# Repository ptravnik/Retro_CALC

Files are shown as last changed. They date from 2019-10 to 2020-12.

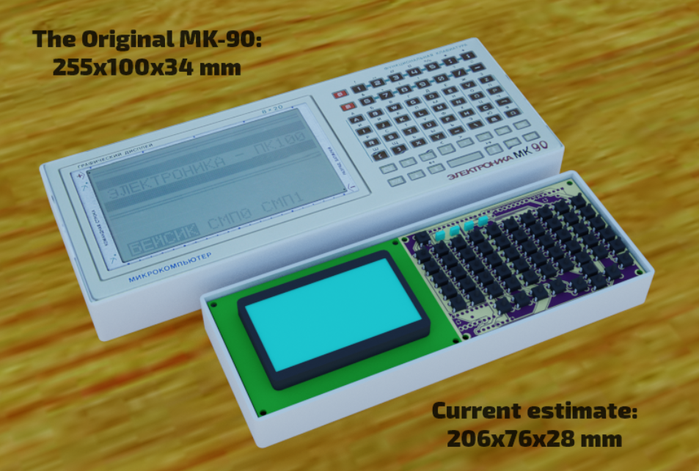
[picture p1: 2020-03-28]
RetroRPN_ESP32/Schematics/Plots/RetroCalculator_Mockup2_Rendering.png

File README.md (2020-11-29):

# Retro_CALC

The ultimate goal is to build a powerful RPN calculator, programmable in BASIC-like language

## The FIRST mockup version:

1. Arduino MEGA 2560
1. [Arduino MEGA SRAM shield](https://hackaday.io/project/21561-arduino-mega-2560-32kb-ram-shield) (my PCB is modified for 56k RAM instead of 32 in the original version)
1. Arduino SD card reader; this version is for Uno, but runs on Mega with pins 10-13 using Soft SPI
1. Piezo speaker on line 9
1. Hardware keyboard on lines A0-A4
1. LCD screen 128x64 pixels on SPI

This code development is abandoned.

## The SECOND mockup version:

1. ESP32 Dev Module
1. Micro SD card reader on VSPI 5, 18, 19, 23
1. Hardware keyboard on lines 25-27 and 32, 33; pin 34 is used for power switch
1. LCD screen 128x64 pixels on HSPI 12-15 
1. Arduino Micro Pro 3.3V, 8 MHz as a "keyboard/mouse injector"

The code is fully ported and tested on the ESP-32 platform. Final version of Keyboard PCB (KBD-2090) has been tested.

## The THIRD mockup version:

1. ESP32 Dev Module
1. Micro SD card reader on VSPI 5, 18, 19, 23
1. Hardware keyboard on lines 25-27 and 32, 33; pin 34 is used for power switch
1. TFT screen 480x320 pixels on HSPI 12-15
1. 2xLiPo batteries (4000 mAh), charger and power management
1. Real-Time Clock based on DS3231 chip
1. Arduino Micro Pro 3.3V, 8 MHz as a "peripheral controller"

This mockup is under development. Both BW LCD and Color TFT are likely to be supported. 

# Build Instructions

## To build for Arduino Mega 2560
1. Tested on Arduino IDE 1.18.10.
1. Install 3 libraries: [U8g2](https://github.com/ptravnik/Retro_CALC/tree/master/U8g2) for the LCD, [SD2](https://github.com/ptravnik/Retro_CALC/tree/master/SD2), and [HWKbd](https://github.com/ptravnik/Retro_CALC/tree/master/HWKbd) for the keyboard. Alternatively just copy the same into the Arduino libraries folder (will not install the examples).
1. Copy the source, [RetroRPN_Arduino](https://github.com/ptravnik/Retro_CALC/tree/master/RetroRPN_Arduino), to any convenient folder and open with Arduino IDE.
1. Select the board as **Arduino Mega or Mega 2560**, processor **ATMega 2560**, compile and upload as usual.

## To build for ESP32 Dev Board
1. Tested on Arduino IDE 1.18.10. and 1.18.12 (VSCode IDE also can be used if Arduino IDE is installed).
1. Install 2 libraries: [U8g2](https://github.com/ptravnik/Retro_CALC/tree/master/U8g2) for the LCD and [HWKbd](https://github.com/ptravnik/Retro_CALC/tree/master/HWKbd) for the keyboard. Alternatively just copy the same into the Arduino libraries folder (will not install the examples).
1. Copy the source, [RetroRPN_ESP32](https://github.com/ptravnik/Retro_CALC/tree/master/RetroRPN_ESP32), to any convenient folder and open with Arduino IDE.
1. Validate which version of hardware keyboard is connected: the production layout uses different h file as the buttons\' position is different from the early mock-up.
1. Select the board as **ESP32 Dev Module**, compile and upload as usual. Dev module requires you to hold **BOOT** down for security reasons; on my module (v 1) this pin is not exposed, so must be done with the button on the module itself. Your board may have this on GPIO 00 pin - wiring to an external button is recommended.

## To build the Keyboard Injector or Peripheral Controller:
1. Tested only with cheap Chinese clones of Sparkfun Pro Micro on Arduino IDE 1.18.10 and 1.18.12.
1. Carefully follow the [install instructions from Sparkfun](https://learn.sparkfun.com/tutorials/pro-micro--fio-v3-hookup-guide/all)
1. Download the [code from github](https://github.com/ptravnik/Retro_CALC/tree/master/Keyboard_Injector_Micro or https://github.com/ptravnik/Retro_CALC/tree/master/MK2090_Peripheral_Controller) 
1. Select the board as **Sparkfun Pro Micro** and the processor as **ATMega 32U4 3.3V, 8MHz** or **ATMega 5.0V 16MHz** version (depending on the one you have); **CAUTION** "Leonardo" may work for 5V / 16 MHz boards, but will surely brick a 3.3V version!
1. Select the board's port
1. Upload to board (shorting Reset to Ground may be required after the interface says "Uploading...")

## Automated testing
1. Place the content of [testing folder](https://github.com/ptravnik/Retro_CALC/tree/master/BASIC_Tests) into the root of the SD card.
1. Insert the SD into the calculator and cycle power button.
1. Upon the calculator wake-up (or new firmware install from the IDE + reboot), issue command **RUN** via Serial Monitor.

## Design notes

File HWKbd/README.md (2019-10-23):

  Hardware keyboard for Arduino with an SPI-like interface
  Copyright (c) 2019 Pavel Travnik.  All right reserved.

  This library is free software; you can redistribute it and/or
  modify it under the terms of the GNU Lesser General Public
  License as published by the Free Software Foundation; either
  version 2.1 of the License, or (at your option) any later version.

  This library is distributed in the hope that it will be useful,
  but WITHOUT ANY WARRANTY; without even the implied warranty of
  MERCHANTABILITY or FITNESS FOR A PARTICULAR PURPOSE.  See the GNU
  Lesser General Public License for more details.

  You should have received a copy of the GNU Lesser General Public
  License along with this library; if not, write to the Free Software
  Foundation, Inc., 51 Franklin St, Fifth Floor, Boston, MA  02110-1301  USA

  Hardware Notes.
  
  The keyboard communicates with Arduino via J1:
  1. POWER - connect to +5 V on Mega or +3.3V on Duo
  2. KBD_RESET - output, any digital pin
  3. KBD_CLOCK - output, any digital pin
  4. KBD_READ - input (no pullup!), any digital pin
  5. LED_RESET - output, any digital pin
  6. LED_CLOCK - output, any digital pin
  7. RESET - connect to Arduino RESET (optional)
  8. GROUND
  To read the keyboard, send a pulse to KBD_RESET and read
  the first button state from KBD_READ (HIGH means "pressed").
  Then, continue sending pulses on KBD_CLOCK to read buttons
  2, 3, 4, etc.
  To set the LEDs, send a pulse to LED_RESET and cycle
  LED_CLOCK from 0 to 15 times, which corresponds to 16 binary states.
  Note that the software presimes that no PWM is sent to the keyboard ports!

  Software Notes.
  The keyboard communicates in UTF-8. The current implementation supports
  8 reading modes:
  0. English character set, small letters, numbers
  1. SHIFT. English character set, capital letters, punctuation marks.
  2. F1 - additional letters and macros in English
  3. F2 - additional letters and macros in English
  4. LANG - national language mode (currently only Cyrillic is implemented)
  5. SHIFT+LANG - capital letters for Cyrillic
  6. F1+LANG - additional letters and macros in national language
  7. F2+LANG - additional letters and macros in national language
  
  The key codes are composed of 16-bit integers, 8 numbers per button
  (by the number of modes). The bit pattern is as following:
  0MMM0000 cccccccc
  1MMMaaaa aaaaaaaa
  MMM - the next mode (from 0 to 7)
  cccccccc - a single-byte Unicode character (if >128, it is a control character, such as an arrow)
  aaaaa aaaaaaaaa - a 12-bit shift in the macros table;
  the latter is composed of null-terminated strings, up to 4k in length.

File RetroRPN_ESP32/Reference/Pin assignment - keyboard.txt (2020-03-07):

Hardware keyboard interfaces:

Primary J1:
1 VDD (3 to 15 Volts are OK, the logic level will change correspondingly)
2 KBD RESET
3 KBD CLOCK
4 KBD READ
5 LED RESET
6 LED CLOCK
7 Host RESET
8 GROUND

J2 is for connecting additional buttons or other devices:
1 VDD (pass-through from J1)
2-11 COLUMNS 0-9
12 ROW 7
13 ROW 8
14 GROUND

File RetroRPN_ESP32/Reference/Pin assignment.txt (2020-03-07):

ESP32 Dev module pins:

// 01 - TX0
// 02 - In-built LED (SD activity)
// 03 - RX0
// 04 - SD insert sensor (DET_A)
// 05 - VSPI CSO - SD Select (DAT3)
// 06 to 11 - NA (Dev module not exposing)
// 12 - HSPI MISO LCD Data (R/W)
// 13 - HSPI MOSI LCD Reset (RESET)
// 14 - HSPI CLK LCD Clock (E)
// 15 - HSPI CSO LCD Select (RS)
// 16 - RX2 (serial to Pro Micro PIN 8)
// 17 - TX2 (serial to Pro Micro PIN 9)
// 18 - VSPI CLK - SD Clock (CLK)
// 19 - VSPI MISO - SD out (DAT0)
// 20 - NA
// 21 - LCD LED PWM
// 22 - LCD POWER (this model does not have sleep)
// 23 - VSPI MOSI - SD command (CMD)
// 24 - NA
// 25 - KBD CLK
// 26 - KBD RST
// 27 - KBD_LED CLK
// 28 to 31 - NA
// 32 - KBD_LED RST
// 33 - KBD DATA
// 34 - POWER ON/OFF
// 35 - (input only) Pro Micro Alive pin 7

Pro Micro pins:

// 07 - Pro Micro is alive
// 08, 09 - TX, RX for software serial
// 10 - optional status pin

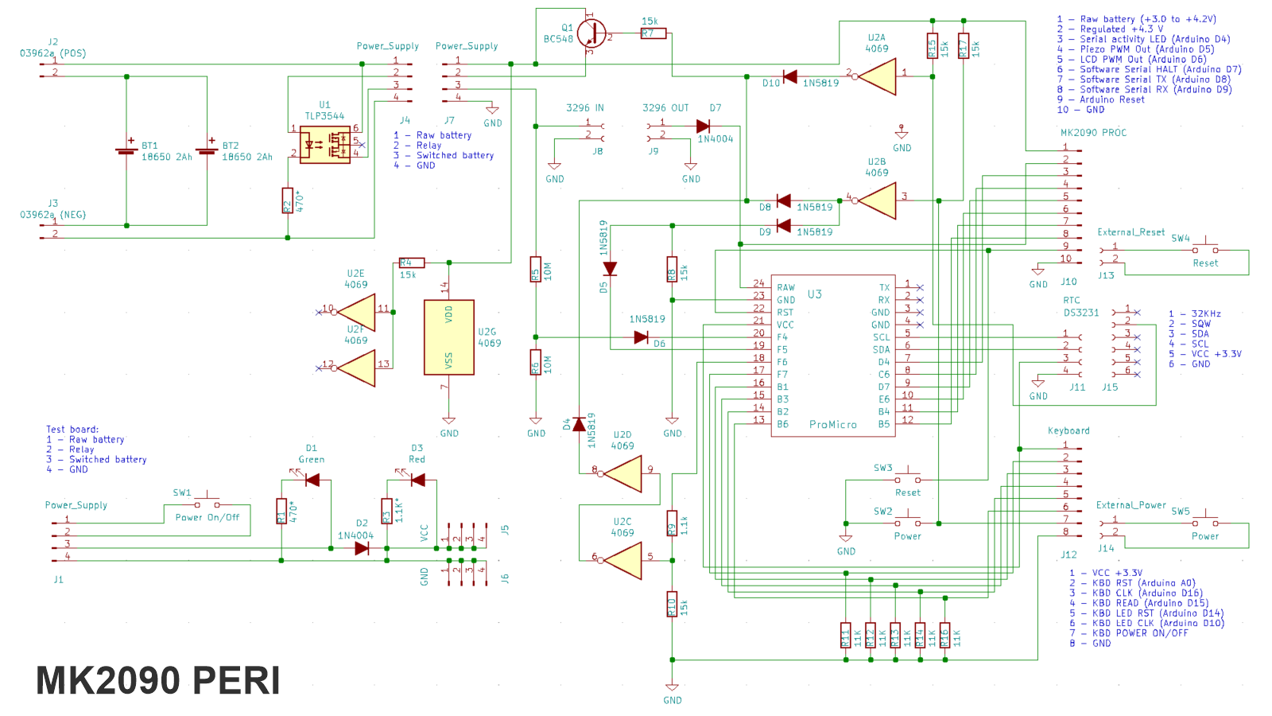
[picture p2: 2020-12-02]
MK2090_Peripheral_Controller/reference/Peripherals_Board_Schematics.png

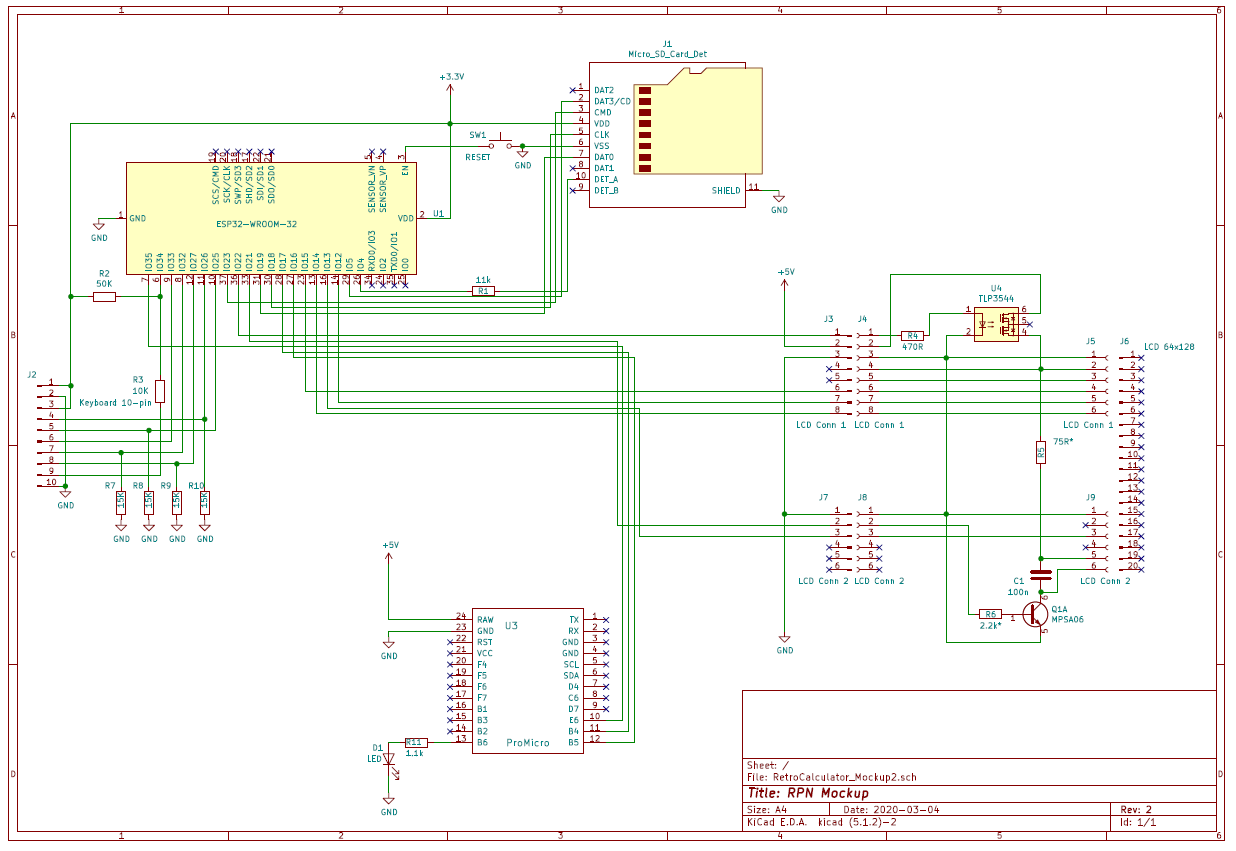
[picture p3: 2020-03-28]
RetroRPN_ESP32/Schematics/Plots/RetroCalculator_Mockup2_Schematics.png

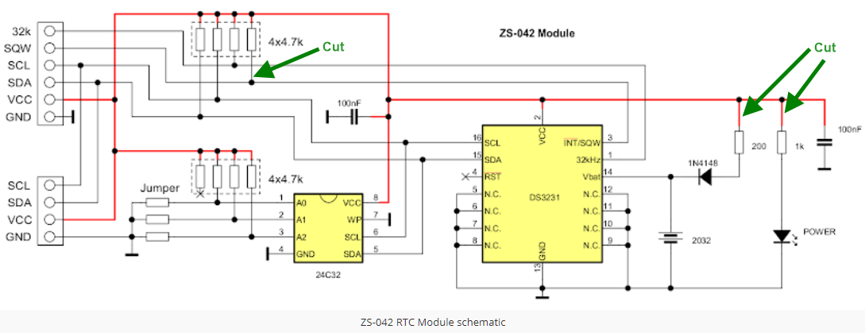
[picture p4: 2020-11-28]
MK2090_Peripheral_Controller/reference/ZS-042 modification.png

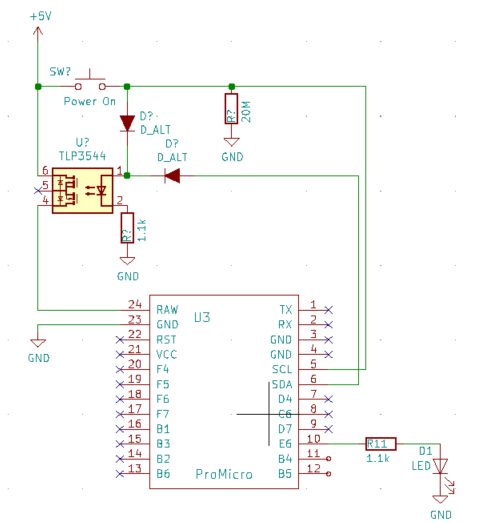
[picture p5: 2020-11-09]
MK2090_Peripheral_Controller/reference/Basic_Power.png

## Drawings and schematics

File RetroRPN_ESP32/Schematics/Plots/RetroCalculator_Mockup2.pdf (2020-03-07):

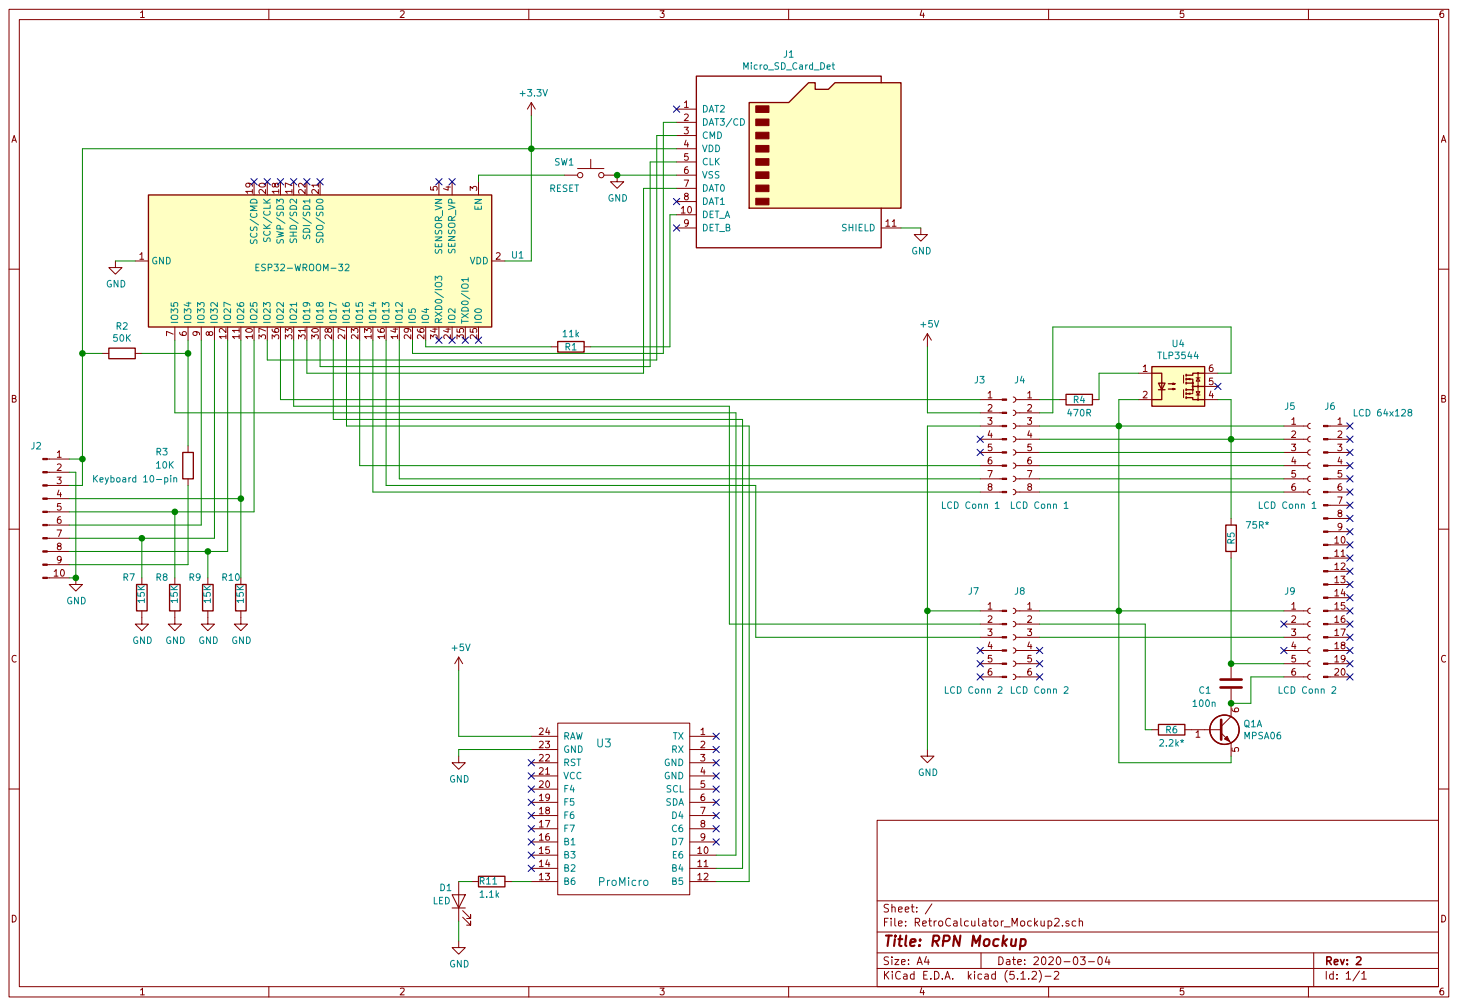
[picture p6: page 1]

9 U1 ESP32-WROOM-32 DAT2 1 DET_A 10 SHIELD 11 DAT3/CD 2 CMD 3 VDD 4 CLK 5 VSS 6 DAT0 7 DAT1 8 DET_B 9

File: RetroCalculator_Mockup2.sch Sheet: /
Id: 1/1 Title: RPN Mockup

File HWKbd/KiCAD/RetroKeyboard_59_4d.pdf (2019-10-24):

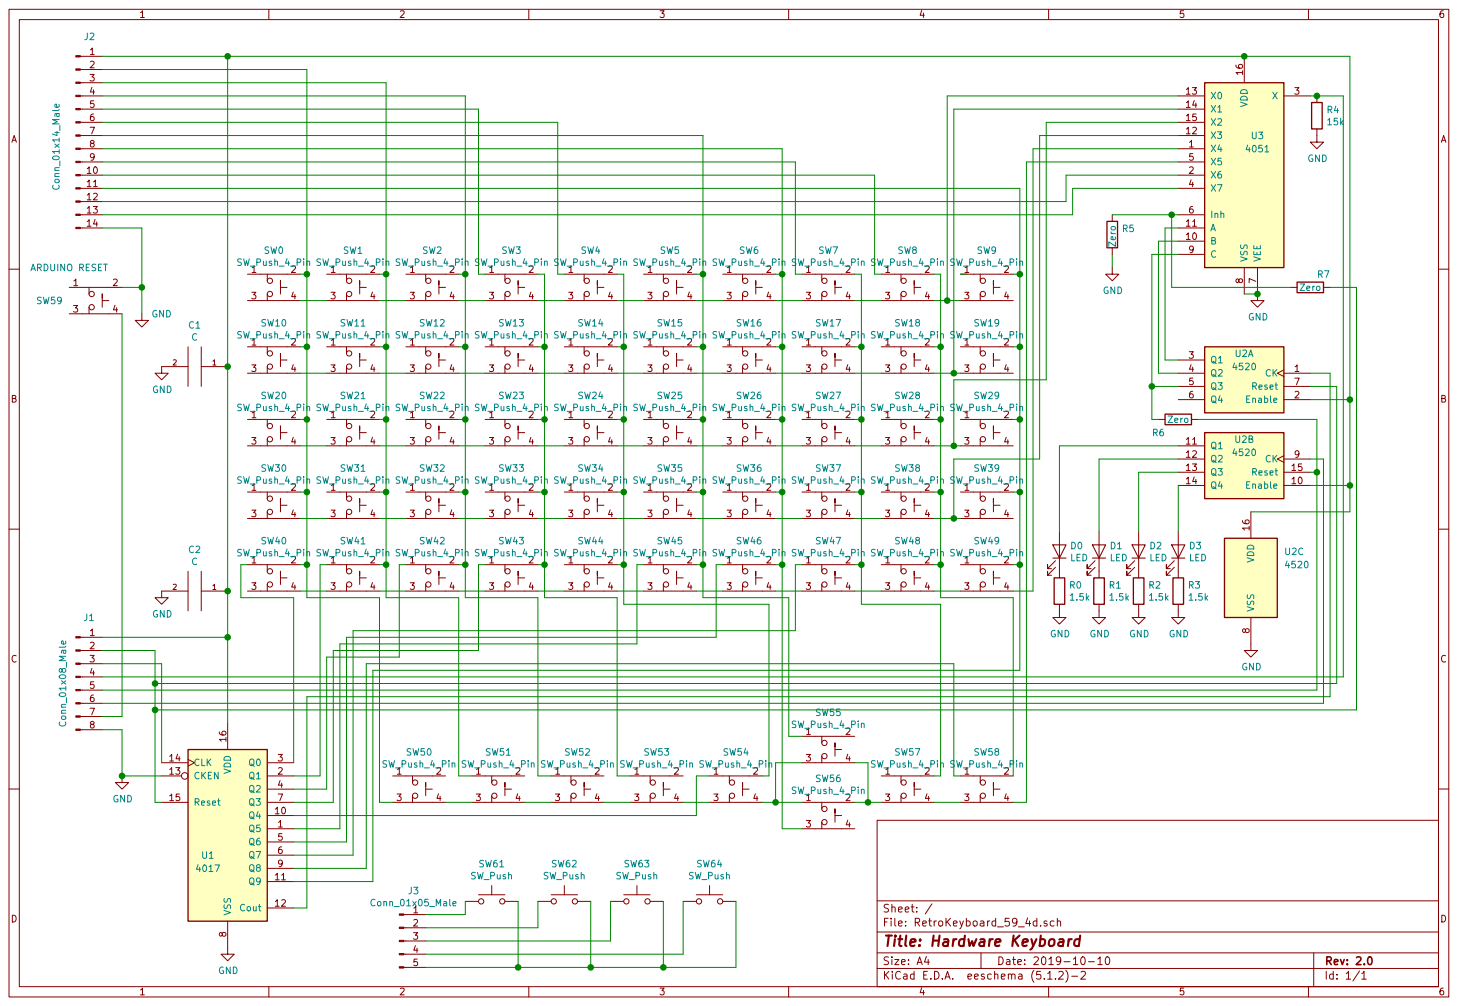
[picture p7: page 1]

Id: 1/1 Title: Hardware Keyboard

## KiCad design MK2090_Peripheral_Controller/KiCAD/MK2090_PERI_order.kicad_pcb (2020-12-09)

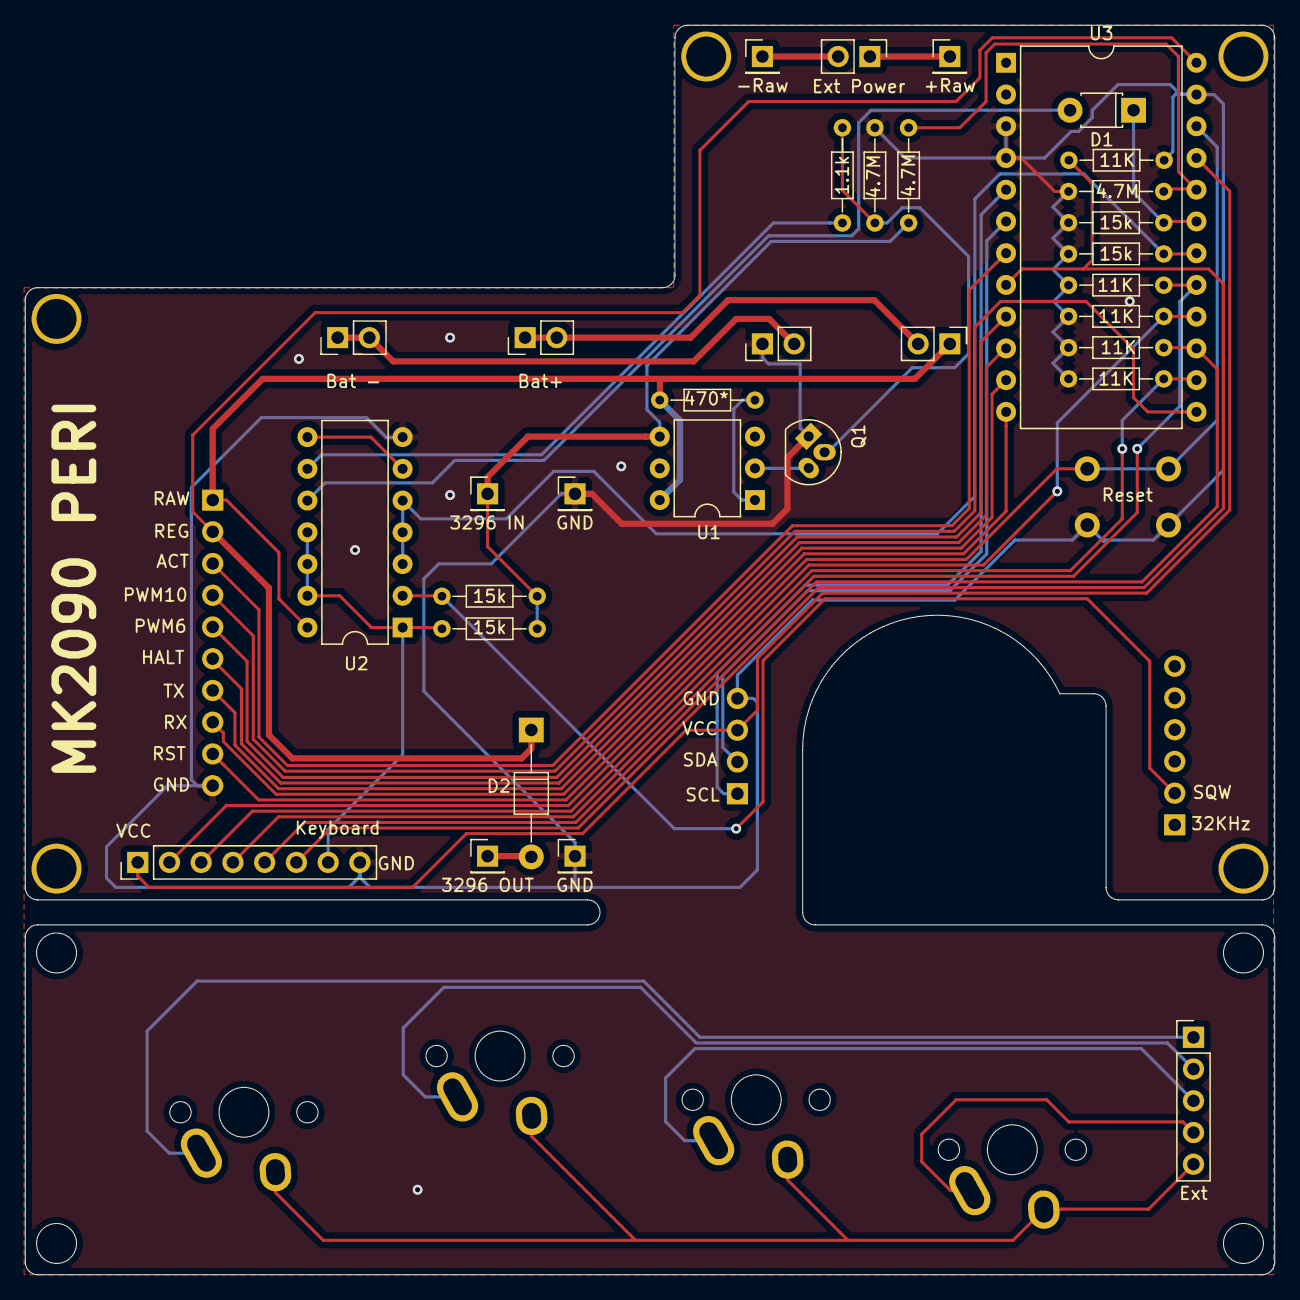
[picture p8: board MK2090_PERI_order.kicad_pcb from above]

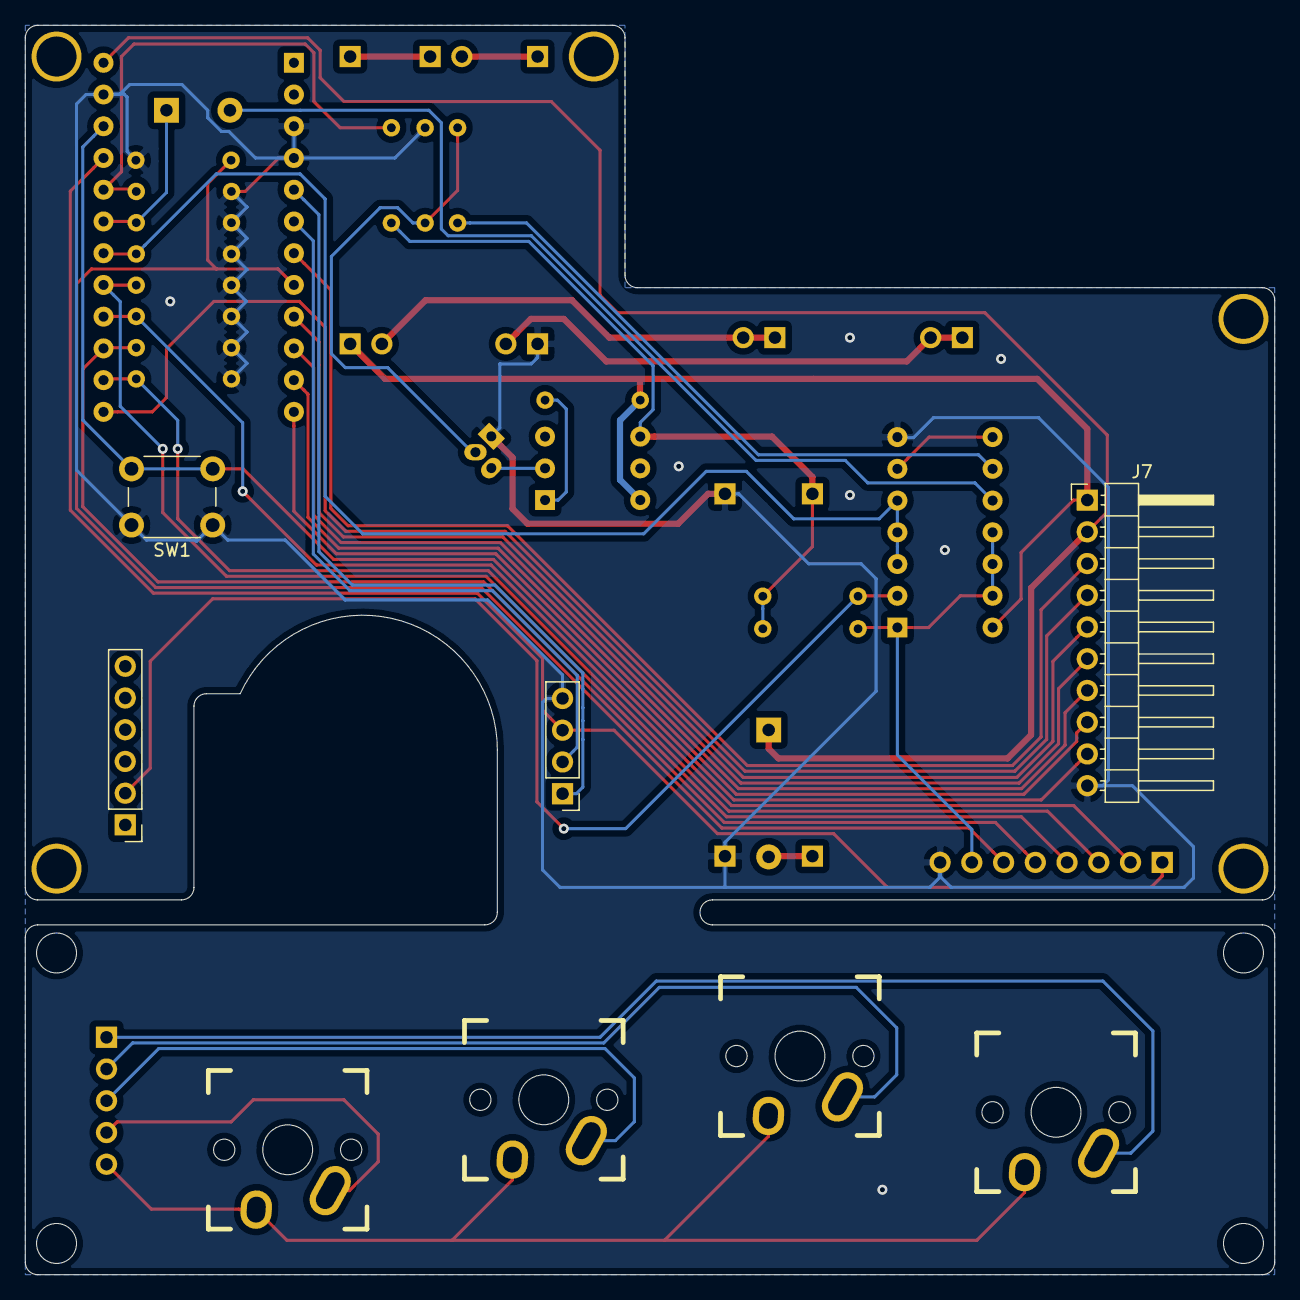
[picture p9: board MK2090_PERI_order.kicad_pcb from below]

Board: 2 copper layers, 100.0 x 100.0 mm, 46 parts (8 on the bottom side), 40 nets.

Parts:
D1: 1N5819; D_T-1_P5.08mm_Horizontal
D2: 1N4004; D_T-1_P10.16mm_Horizontal
HOLE_M3, HOLE_M3#2, HOLE_M3#3, HOLE_M3#4, HOLE_M3#5: VAL**; HOLE_M3
J1: +Raw; Pin_Header_Straight_1x01_Pitch2.54mm
J2: -Raw; Pin_Header_Straight_1x01_Pitch2.54mm
J3: 03962a (POS); Pin_Header_Straight_1x02_Pitch2.54mm
J4: 03962a (NEG); Pin_Header_Straight_1x02_Pitch2.54mm
J5: 3296 IN; Pin_Header_Straight_1x01_Pitch2.54mm
J6, J12: GND; Pin_Header_Straight_1x01_Pitch2.54mm
J7: MK2090 PROC; Pin_Header_Angled_1x10_Pitch2.54mm
J8: Keyboard; Pin_Header_Straight_1x08_Pitch2.54mm
J9: RTC; Pin_Header_Straight_1x04_Pitch2.54mm
J10: DS3231; Pin_Header_Straight_1x06_Pitch2.54mm
J11: 3296 OUT; Pin_Header_Straight_1x01_Pitch2.54mm
J13: Ext Power; Pin_Header_Straight_1x02_Pitch2.54mm
J14: Bat+; Pin_Header_Straight_1x02_Pitch2.54mm
J15: Bat -; Pin_Header_Straight_1x02_Pitch2.54mm
J16: Ext; Pin_Header_Straight_1x05_Pitch2.54mm
Q1: 2N7000; TO-92_Molded_Narrow_Oval
R1: 470*; R_Axial_DIN0204_L3.6mm_D1.6mm_P7.62mm_Horizontal
R2, R7, R8: 4.7M; R_Axial_DIN0204_L3.6mm_D1.6mm_P7.62mm_Horizontal
R3: 1.1k; R_Axial_DIN0204_L3.6mm_D1.6mm_P7.62mm_Horizontal
R4, R5, R6, R9: 15k; R_Axial_DIN0204_L3.6mm_D1.6mm_P7.62mm_Horizontal
R10, R11, R12, R13, R14: 11K; R_Axial_DIN0204_L3.6mm_D1.6mm_P7.62mm_Horizontal
SW1: Reset; SW_PUSH_6mm
SW2: E; Mx_Alps_100
SW3: A; Mx_Alps_100
SW4: L; Mx_Alps_100
SW5: Spec; Mx_Alps_100
U1: TLP3544; DIP-6_W7.62mm
U2: 4023; DIP-14_W7.62mm
U3: ProMicro; DIP-24_W15.24mm

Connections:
GND: J4.1, J6.1, J7.10, J8.8, J9.4, J12.1, Q1.1, R2.1, R6.1, R8.1, R9.1, R10.1, R11.1, R12.1, R13.1, R14.1, SW1.1, U2.7, U3.3, U3.4, U3.23
unnamed: D1.1, R9.2, U3.19
unnamed: D1.2, U2.10
unnamed: D2.1, J7.2, U3.24
unnamed: D2.2, J11.1
unnamed: J1.1, J13.1
unnamed: J3.1, J7.1, R1.2, U1.6, U2.14
unnamed: J5.1, R4.2, R5.2, R7.2, U1.4
unnamed: J7.3, U3.7
unnamed: J7.4, U3.13
unnamed: J7.5, U3.9
unnamed: J7.6, U3.10
unnamed: J7.7, U3.11
unnamed: J7.8, U3.12
unnamed: J7.9, SW1.2, U3.22
unnamed: J8.1, J9.3, U3.21
unnamed: J8.2, R11.2, U3.16
unnamed: J8.3, R13.2, U3.14
unnamed: J8.4, R10.2, U3.17
unnamed: J8.5, R12.2, U3.15
unnamed: J8.6, R14.2, U3.8
unnamed: J8.7, R4.1, U2.1, U2.11, U2.12, U2.13
unnamed: J9.1, U3.5
unnamed: J9.2, U3.6
unnamed: J10.2, R5.1, U2.2
unnamed: J2.1, J13.2
unnamed: J3.2, J14.1, J14.2
unnamed: J4.2, J15.1, J15.2
unnamed: J16.1, SW2.1
unnamed: J16.2, SW3.1
unnamed: J16.3, SW4.1
unnamed: J16.4, SW5.1
unnamed: J16.5, SW2.2, SW3.2, SW4.2, SW5.2
unnamed: Q1.2, R2.2, R3.1
unnamed: Q1.3, U1.2
unnamed: R1.1, U1.1
unnamed: R3.2, U2.9
unnamed: R6.2, U2.3, U2.4, U2.5, U3.18
unnamed: R7.1, R8.2, U3.20
unnamed: U2.6, U2.8

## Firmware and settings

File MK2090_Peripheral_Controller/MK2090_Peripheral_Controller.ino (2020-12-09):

////////////////////////////////////////////////////////

/* RetroRPN - "Электроника МК-90" reborn
  Copyright (c) 2020 Mike Yakimov.  All rights reserved.

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
  You should have received a copy of the GNU Lesser General Public
  License along with this library; if not, write to the Free Software
  Foundation, Inc., 51 Franklin St, Fifth Floor, Boston, MA  02110-1301  USA
*/

////////////////////////////////////////////////////////
//
// This is a hardware companion to ESP32 Retro Calculator (modern reincarnation of the Soviet Электроника-90) 
// Implementation is for Sparkfun Micro Pro module (3.3 V) or valid clones
//
// Functionality:
// (1) Receive inputs from PC via USB Serial, perform conversion from UTF8 to CP1251, send to Software Serial
// (2) Receive inputs from Software Serial, perform conversion from CP1251 to UTF8, send to USB Serial
// (3) Receive inputs from Software Serial, send to PC as keystrokes (Via Arduino Keyboard library)
// (4) Receive inputs from Software Serial, send to PC as mouse movements/clicks (Via Arduino Mouse library)
// (5) Receive commands from Software Serial, play tones via piezo speaker
// (6) Receive commands from Software Serial, access time module (set/retrive time)
// (7) Constantly monitor hardware keyboard, convert inputs to CP1251, bufferize with USB serial
// (8) Receive commands from Software Serial, perform immediate hardware keyboard scan, return scancodes
// (9) Receive commands from Software Serial, set and reytrieve hardware keyboard LEDs
// (10) Receive commands from Software Serial, manipulate LCD PWM
// (11) Receive commands from Software Serial, perform power shutdown 
//
// Pin assignment:
//
// 00 - TX0 (Not connected)
// 01 - RX1 (Not connected)
// 02 - SDA to DS3231 RT Clock module
// 03 - SCL to DS3231
// 04 - Serial activity LED
// 05 - KBD LED Clock 
// 06 - LCD PWM Out (note: 5 and 6 do not support low duty cycles, but this is not required)  
// 07 - Software Serial / operation Block
// 08 - Software Serial TX
// 09 - Software Serial RX (Choice for RX: 8, 9, 10, 11, 14 (MISO), 15 (SCK), 16 (MOSI)) 
// 10 - Piezo PWM Out (note: low duty cycle is required)
// 14 - KBD LED Reset (Also MISO for ISP programming)
// 15 - KBD Reset (Also SCK for ISP programming)
// 16 - KBD Clock (Also MOSI for ISP programming)
// A0 - KBD Sense
// A1 - Power Hold
// A2 - Power Button Sense (HIGH - shutdown wanted)
// A3 - Battery voltage sensor
//
////////////////////////////////////////////////////////

#include <Arduino.h>
#include <SoftwareSerial.h>
#include <Keyboard.h>
#include <Mouse.h>

#include "./src/CP1251_mod.h" 
#include "./src/SelfShutdown.hpp"
#include "./src/ActivityLED.hpp"
#include "./src/PiezoController.hpp"
#include "./src/PWMController.hpp"
#include "./src/VoltageSensor.hpp"
#include "./src/CircularBuffer.hpp"
#include "./src/DS3231.hpp"
#include "./src/Commander.hpp"

// Uncomment for debugging
//#define __DEBUG
//#define __DEBUG_CODES

#define PC_BAUD 115200
#define SERIAL_BAUD 38400

#define RTC_SDA             2
#define RTC_SCL             3
#define ACTIVITY_LED        4
#define LED_CLK             5
#define LCD_PWM_OUT         6
#define ACTIVITY_TO_ESP32   7
#define SERIAL_TX           8
#define SERIAL_RX           9
#define PIEZO_PWM_OUT       10
#define LED_RESET           14
#define KBD_RESET           15
#define KBD_CLK             16
#define KBD_SIG             A0
#define SELF_POWER_HOLD     A1
#define POWER_OFF           A2
#define BATTERY_VOLTAGE     A3

#define N_TEST_LOOPS        100

#define _SS_MAX_RX_BUFF 256
SoftwareSerial mySerial(SERIAL_RX, SERIAL_TX);

//#define UTF8_BUFFER_LENGTH 64
//static byte UTF8_buffer[UTF8_BUFFER_LENGTH];
//static byte CP1251_buffer[UTF8_BUFFER_LENGTH];

//#define N_SUBS 3
//const byte _PLSMNS_SUB[] PROGMEM = { '+', '/', '-', _NUL_};
//const byte _YO_SUB[] PROGMEM = { 0xD1, 0x91, _NUL_};
//const byte _YO_CAP_SUB[] PROGMEM = { 0xD0, 0x81, _NUL_};

//const byte _CP1251_bytes[] PROGMEM = {
//  _PLSMNS_, 
//  0xB8, // small "YO"
//  0xA8  // capital "YO"
//  };
//const byte *const _CP1251_substitutes[] PROGMEM = {
//  _PLSMNS_SUB, 
//  _YO_SUB, 
//  _YO_CAP_SUB, 
//  };

static SelfShutdown myShutdown;
static ActivityLED myActivityLED;
static PiezoController myPiezoController;
static PWMController myPWMController;
static VoltageSensor myVoltageSensor;
static DS3231_Controller myDS3231;
static CircularBuffer cb;
static Commander comm;
static volatile int loopCount = N_TEST_LOOPS;

//
// Runs once, upon the power-up
//
void setup() {
    myShutdown.begin( POWER_OFF, SELF_POWER_HOLD);
    myPiezoController.begin(PIEZO_PWM_OUT);
    myPWMController.begin( LCD_PWM_OUT);

    pinMode( ACTIVITY_TO_ESP32, OUTPUT);
    digitalWrite( ACTIVITY_TO_ESP32, LOW);

    myActivityLED.begin( ACTIVITY_LED);
    myVoltageSensor.begin( BATTERY_VOLTAGE, 6600, 0); // We use 20M:20M dividor and 3.3 V processor
    myDS3231.begin();

    Serial.begin(PC_BAUD);
    while(Serial.available()) Serial.read();
    mySerial.begin(SERIAL_BAUD);
    while(mySerial.available()) mySerial.read();
    Mouse.begin();
    Keyboard.begin();

    comm.begin( &cb);
    comm.addCommand( (byte)COMMAND_SET_DATETIME, setDateTime); //AYYMMDDHHMMSS
    comm.addCommand( (byte)COMMAND_GET_DATETIME, getDateTime); //B
    comm.addCommand( (byte)COMMAND_GET_TEMPERATURE, getTemperature); //C
    comm.addCommand( (byte)COMMAND_GET_VOLTAGE, getBatteryVoltage); //D
    comm.addCommand( (byte)COMMAND_SHUTDOWN, orderShutdown); //F
    comm.addCommand( (byte)COMMAND_SETWAKEUP, setWakeUp); //GDDHHMMSS
    comm.addCommand( (byte)COMMAND_GETWAKEUP, getWakeUp); //H
    comm.addCommand( (byte)COMMAND_SETLCDDUTYCYCLE, setLCDDuty); //Iddd
    comm.addCommand( (byte)COMMAND_GETLCDDUTYCYCLE, getLCDDuty); //J
    comm.addCommand( (byte)COMMAND_PLAYTONE, playTone); //Kffffddd

    delay(50);
    for( byte i=0; i<3; i++) myActivityLED.blink( 30, 50);

    //lastActive = millis();
    // permission to communicate granted to ESP32
    digitalWrite( ACTIVITY_TO_ESP32, HIGH);
}

//
// Runs continuously
//
void loop() {
    checkShutdown();

    //Serial.print( "Battery Voltage = ");
    //Serial.println( myVoltageSensor.read());
    //readRTC();
    comm.read();
    delay(500);

    // Eliminate unwanted Tx, Rx lights
    RXLED0;
    TXLED0;
    myActivityLED.blink( 100, 100);
    
    loopCount--;
    if( loopCount > 1) return;

    // Proceed to programmatic shutdown
    DS3231_DateTime dt = myDS3231.getDateTime();
    myDS3231.setWakeUp( dt.getNextAlarm( 300)); // wake up in 5 minutes
    
    for(uint8_t i=0; i<=100; i+=10){
        myPWMController.set( i);
        myPiezoController.play( 1000, 100);
    }
    myShutdown.shutdown();

    // char c = 0;
    // long t = millis();
    // blink_Activity();
    // if( Serial.available()){
    //   lastActive = t;
    //   c = Serial.read();
    //   if( c != 0)
    //     sendToESP32Serial(c);
    // }
    // while( mySerial.available()){
    //   c = mySerial.read();
    //   if( !sendToPCKeyboard(c) && c!=0)
    //     cb.push(c);
    // }
    // while( cb.available()){
    //   lastActive = t;
    //   Serial.write(cb.pop());
    // }
}

void checkShutdown(){
    if( !myShutdown.isPowerPressed()) return;
    Serial.println( "Shutdown key, but USB on...");

    // This code is for checking the wake-up functionality
    DS3231_DateTime dt = myDS3231.getDateTime();
    myDS3231.setWakeUp( dt.getNextAlarm( 300)); // wake up in 5 minutes

    for( int i=10; i>=1; i--)
        myActivityLED.blink( i*10, i*10);
    myShutdown.shutdown();
}

void setDateTime( char *buff, byte n){
    getCommand(buff, n);
    DS3231_DateTime dt = DS3231_DateTime((const char*)buff);
    dt.printHI( buff, n);
    myDS3231.setDateTime(dt);
}

void getDateTime( char *buff, byte n){
    DS3231_DateTime dt = myDS3231.getDateTime();
    #ifdef __DEBUG
    Serial.println( dt.daysSince2000_01_01());
    #endif
    dt.printHI( buff, n);
}

void getTemperature( char *buff, byte n){
    DS3231_Temperature temp = myDS3231.getTemperature();
    temp.printHI( buff, n);
}

void getBatteryVoltage( char *buff, byte n){
    myVoltageSensor.read();
    myVoltageSensor.printHI( buff, n);
}

void orderShutdown( char *buff, byte n){
    snprintf_P(buff, n,
        PSTR("Shutdown from ESP32, but USB on..."));
    for( int i=10; i>=1; i--)
        myActivityLED.blink( i*10, i*10);
    myShutdown.shutdown();
}

void setWakeUp( char *buff, byte n){
    getCommand(buff, n);
    DS3231_Alarm alr = DS3231_Alarm((const char*)buff);
    alr.printHI( buff, n);
    myDS3231.setWakeUp(alr);
}

void getWakeUp( char *buff, byte n){
    DS3231_Alarm alr = myDS3231.getWakeUp();
    alr.printHI( buff, n);
}

void setLCDDuty( char *buff, byte n){
    getCommand(buff, n);
    myPWMController.set( (const char *)buff);
    myPWMController.printHI( buff, n);
}

void getLCDDuty( char *buff, byte n){
    myPWMController.printHI( buff, n);
}

void playTone( char *buff, byte n){
    getCommand(buff, n);
    myPiezoController.play( buff, n);
    myPiezoController.print( buff, n);
}

void getCommand(char *buff, byte n){
    char *ptr = buff;
    for( byte i=0; i<n-1; i++){
        if( !Serial.available()) break;
        char c = Serial.read();
        if( c == _CR_) break;
        *ptr++ = c;
    }
    *ptr = _NUL_;
}

// //
// // Converts the keyboard injection command
// // Returns true if injected
// //
// bool sendToPCKeyboard( char c){
//   if( c != _KBD_INJ_ && c != _MOUSE_INJ_) return false;
//   if( c == _KBD_INJ_) return processKbdInject();
//   return processMouseInject();
// }
// bool processKbdInject(){
//   for( byte i=0; i<100; i++){
//     if( !mySerial.available()){
//       delayMicroseconds(200);
//       continue;
//     }
//     byte c = (byte)mySerial.read();
//     if( c < _BEL_) return false;
//     Keyboard.write(c);
//     return true;
//   }
//   // no command in 100 ms: misplaced inject
//   return false;
// }
// bool processMouseInject(){
//   for( byte i=0; i<100; i++){
//     if( !mySerial.available()){
//       delayMicroseconds(200);
//       continue;
//     }
//     byte c = (byte)mySerial.read();
//     byte command = c & 0x03; // two lower bytes are the command
//     c >>= 2;
//     int delta = (int)c - 31; 
//     switch(command){
//       case 0: // buttons click
//         if( c & 0x1) Mouse.click(MOUSE_LEFT);
//         if( c & 0x2) Mouse.click(MOUSE_RIGHT);
//         if( c & 0x4) Mouse.click(MOUSE_MIDDLE);
//         return true;
//       case 1: // movement x
//         Mouse.move( delta, 0, 0);
//         return true;
//       case 2: // movement y
//         Mouse.move( 0, delta, 0);
//         return true;
//       case 3: // movement z
//         Mouse.move( 0, 0, delta);
//         return true;
//       default:
//         break;
//     }
//     return true;
//   }
//   // no command in 100 ms: misplaced inject
//   return false;
// }

// //
// // Converts message from Unicode to CP1251
// //
// #ifdef __DEBUG
// void _reportUnknownUnicode( byte *ptr){
//   ptr--;
//   Serial.print( "Unknown unicode: ");
//   Serial.print( *ptr++, HEX);        
//   Serial.print( " ");        
//   Serial.print( *ptr++, HEX);        
//   Serial.print( " ");        
//   Serial.print( *ptr++, HEX);        
//   Serial.print( " ");        
//   Serial.println( *ptr++, HEX);        
// };
// #endif
// byte *_addCh( byte* ptr, byte* ptr_limit, byte c){
//   if( ptr >= ptr_limit) return ptr_limit;
//   *ptr++ = c;
//   return ptr;
// }
// char *convertToCP1251( byte *buff, char *message, size_t limit){
//   byte c;
//   byte Unicode_Prefix = 0;
//   byte *ptr1 = buff; 
//   byte *ptr2 = (byte *)message; 
//   byte *ptr_limit = ptr1 + limit - 1; 
//   for (byte i=0; i<strlen(message); i++) {
//     c = *ptr2++;
//     switch(Unicode_Prefix){
//       case 0: // No prefix
//         if( !c) // safety termination
//           return _addCh(ptr1, ++ptr_limit, (byte)0);
//         if( c < 128){ // lower chars
//           ptr1 = _addCh(ptr1, ptr_limit, c);
//           break;
//         }
//         Unicode_Prefix = c;
//         break;
//       case 0xD0:
//         Unicode_Prefix = 0;
//         if( 0x90 <= c && c < 0xD0){
//           ptr1 = _addCh(ptr1, ptr_limit, c + 0x30);
//           break;
//         }
//         if( c == 0x81){
//           ptr1 = _addCh(ptr1, ptr_limit, 0xA8);
//           break;
//         }
//         ptr1 = _addCh(ptr1, ptr_limit, c);
//         break;
//       case 0xD1:
//         Unicode_Prefix = 0;
//         if( 0x80 <= c && c < 0x90){
//           ptr1 = _addCh(ptr1, ptr_limit, c + 0x70);
//           break;
//         }
//         if( c == 0x91){
//           ptr1 = _addCh(ptr1, ptr_limit, 0xB8);
//           break;
//         }
//         ptr1 = _addCh(ptr1, ptr_limit, c);
//         break;
//       case 0xC2:
//         Unicode_Prefix = 0;
//         if( c == 0xAB || c == 0xBB){ // quote
//           ptr1 = _addCh(ptr1, ptr_limit, '\"');
//           break;
//         }
//         #ifdef __DEBUG
//         _reportUnknownUnicode( ptr2);
//         #endif
//         ptr1 = _addCh(ptr1, ptr_limit, UNKNOWN_UTF8);
//         break;
//       case 0xE2:
//         Unicode_Prefix = 0;
//         if( c == 0x80 && *ptr2 == 0x94){ // EM-dash
//           ptr1 = _addCh(ptr1, ptr_limit, '-');
//           ptr1 = _addCh(ptr1, ptr_limit, '-');
//           ptr2++;
//           break;
//         }
//         if( c == 0x80 && *ptr2 == 0xA6){ // triple dot
//           ptr1 = _addCh(ptr1, ptr_limit, '.');
//           ptr1 = _addCh(ptr1, ptr_limit, '.');
//           ptr1 = _addCh(ptr1, ptr_limit, '.');
//           ptr2++;
//           break;
//         }
//         #ifdef __DEBUG
//         _reportUnknownUnicode( ptr2);
//         #endif
//         ptr1 = _addCh(ptr1, ptr_limit, UNKNOWN_UTF8);
//         ptr2++;
//         break;
//       default: // Unknown Unicode is replaced with *
//         Unicode_Prefix = 0;
//         #ifdef __DEBUG
//         _reportUnknownUnicode( ptr2);
//         #endif
//         ptr1 = _addCh(ptr1, ptr_limit, UNKNOWN_UTF8);
//         break;
//     }
//   } // for
//   // safe string termination
//   return _addCh(ptr1, ++ptr_limit, (byte)0);
// }

// //
// // Sends characters to ESP32 serial port
// // Conversion from UTF8 to CP1251 performed
// // Returns the number of chars sent
// //
// byte sendToESP32Serial(char cc){
//   byte c = (byte)cc;
//   if( 0 < c && c < 128){
//     #ifdef __DEBUG
//     // loopback
//     Serial.write(cc);
//     #endif
//     mySerial.write(cc);
//     return 1;
//   }
//   char *ptr = (char *)UTF8_buffer;
//   *ptr++ = cc;
//   *ptr = _NUL_;
//   switch( c){
//     case _NUL_:
//       return 0;
//     case 0xD0: // double character (Russian letters)
//     case 0xD1: // double character (Russian letters)
//     case 0xC2: // double character (quotations)
//       if( !readNonlocking(ptr)) return 0;
//       return _sendToESP32();
//     case 0xE2: // triple character (Ellipsis and EM-dash)
//       if( !readNonlocking(ptr++)) return 0;
//       if( !readNonlocking(ptr)) return 0;
//       return _sendToESP32();
//     default: // unknown or misplaced Unicode is a star!
//       #ifdef __DEBUG
//       // loopback
//       Serial.write(UNKNOWN_UTF8);
//       #endif
//       mySerial.write(UNKNOWN_UTF8);
//       break;
//   }
//   return 0;
// }
// bool readNonlocking(byte *ptr){
//   for( byte i=0; i<100; i++){
//     if( !Serial.available()){
//       delayMicroseconds(100);
//       continue;
//     }
//     *ptr++ = (byte)Serial.read();
//     *ptr = _NUL_;
//     return true;
//   }
//   return false;
// }
// byte _sendToESP32(){
//   #ifdef __DEBUG
//   // loopback
//   Serial.println( (char *)UTF8_buffer);
//   #endif
//   #ifdef __DEBUG_CODES
//   Serial.print( "From [");
//   for( byte i=0; i<UTF8_BUFFER_LENGTH; i++){
//     byte c = UTF8_buffer[i];
//     if( c == _NUL_) break;
//     Serial.print( c, HEX);    
//   }
//   Serial.println( "]");
//   #endif
//   convertToCP1251( CP1251_buffer, (char *)UTF8_buffer, UTF8_BUFFER_LENGTH-1);
//   #ifdef __DEBUG_CODES
//   Serial.print( "To [");
//   for( byte i=0; i<UTF8_BUFFER_LENGTH; i++){
//     byte c = CP1251_buffer[i];
//     if( c == _NUL_) break;
//     Serial.print( c, HEX);    
//   }
//   Serial.println( "]");
//   #endif
//   char *ptr = (char *)CP1251_buffer;
//   for( byte i=0; i<UTF8_BUFFER_LENGTH; i++){
//     if(*ptr == 0) return i;
//     mySerial.write( *ptr++);        
//   }
//   return UTF8_BUFFER_LENGTH-1;
// }

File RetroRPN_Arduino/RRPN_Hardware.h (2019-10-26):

/////////////////////////////////////////////////////
//
// ARMEBA - Arduino Mega Basic 
//
/////////////////////////////////////////////////////

#include <math.h>
#include <SPI.h>
#include <HWKbd.h>
#include <Cyrillic_Phonetic.h>
#include <RPN_Calc_Encoding.h>
#include "LCD_Console.h"
#include "RRPN_Parser.h"
#include "RRPN_Calculator.h"

// Older SD library is used, so can use software SPI in the mockup
#include "SD2.h"

// Store strings in program memory to save RAM
// This is required only for Arduino; ESP32 implements it better
#ifdef __AVR__
#include <avr/pgmspace.h>
#else
#include <pgmspace.h>
#endif

/////////////////////////////////////////////////////
//
// EXTERNAL RAM
//
// This implementation is for a single bank of 56 kB
// external memory. The external memory address starts
// on Arduino Mega at 0x2200
//
/////////////////////////////////////////////////////

#define XRAM_ENABLE_PIN 38
#define XRAM_START ((void *)0x2200)
#define XRAM_END ((void *)0xFFFF)
#define XRAM_SIZE 56200L

//
// Enables and disables memory
//
#define XRAM_ENABLE() digitalWrite( XRAM_ENABLE_PIN, HIGH)
#define XRAM_DISABLE() digitalWrite( XRAM_ENABLE_PIN, LOW)

static const byte XRAM_TOTAL_MSG[]           PROGMEM = " XRAM total  : ";
static const byte XRAM_AVAILABLE_MSG[]       PROGMEM = " XRAM free   : ";

//static volatile byte *program_Memory = reinterpret_cast<volatile byte*>(XRAM_START);


/////////////////////////////////////////////////////
//
// HARDWARE KEYBOARD
//
// This implementation is for a 60-key micro keyboard
//
/////////////////////////////////////////////////////

static HWKbd hwKeyboard;
//static HWKbd_Encoder hwEncoder(
//  HWKBD_Codepage_Cyrillic_Phonetic_UTF8,
//  HWKBD_Macropage_Cyrillic_Phonetic_UTF8);
static HWKbd_Encoder hwEncoder(
  HWKBD_Codepage_RPN,
  HWKBD_Macropage_RPN);

/////////////////////////////////////////////////////
//
// SD CARD READER
//
// This implementation is for a SD card reader on
// "soft" SPI pins 10, 11, 12, 13
// (The hardware SPI is used for the LCD display.)
// Due to the way the SD Library works,
// pin 10 always needs to be an output, even when
// your shield uses another line for CS
// SD cards on Arduino are not hot-swappable
//
// * SD card attached to SPI bus as follows:
// ** UNO:  MOSI - pin 11, MISO - pin 12, CLK - pin 13, CS - pin 4 (CS pin can be changed)
//  and pin #10 (SS) must be an output
// ** Mega:  MOSI - pin 51, MISO - pin 50, CLK - pin 52, CS - pin 4 (CS pin can be changed)
//  and pin #52 (SS) must be an output
// ** Leonardo: Connect to hardware SPI via the ICSP header
//
/////////////////////////////////////////////////////

// this turns on "autorun" feature
#define SD_AUTORUN 1
//#undef SD_AUTORUN
#define SD_FILE_NAME_MAX  65
#define IO_BUFFER_LENGTH  256

static const byte SD_AUTORUN_NAME[]  PROGMEM = "autorun.bas";
static const byte SD_RPN_STORAGE[]   PROGMEM = "_rpnstack.dat";
static const byte SD_ERROR_MSG[]     PROGMEM = " SD card error";
static const byte SD_NOTFOUND_MSG[]  PROGMEM = " Not found: ";
static const byte SD_NOTDIR_MSG[]    PROGMEM = " Not a dir: ";
static const byte SD_LISTING_MSG[]   PROGMEM = " List: ";
static const byte SD_LOADING_MSG[]   PROGMEM = " Load: ";
static const byte SD_SAVING_MSG[]    PROGMEM = " Save: ";
static const byte SD_MAKING_MSG[]    PROGMEM = " Make: ";
static const byte SD_DIR_MSG[]       PROGMEM = "(dir)";
static const byte SD_SLASH_MSG[]     PROGMEM = "/";
static const byte SD_SPACE_MSG[]     PROGMEM = " ";
static const byte SD_INDENT_MSG[]    PROGMEM = " ";
static const byte SD_DEFAULT_EXT[]   PROGMEM = ".bas";

static bool SD_initialized = false;
static char SD_filename[SD_FILE_NAME_MAX];
static char SD_directory[SD_FILE_NAME_MAX];

static File SD_File_In; // will be used later in data logging
static File SD_File_Out;
static bool SD_File_In_Enabled = false;
static bool SD_File_Out_Enabled = false;
static byte IO_Buffer[IO_BUFFER_LENGTH];

/////////////////////////////////////////////////////
//
// EEPROM STORAGE
//
// This implementation is for an in-built (E)EPROM storage
// Only enable if available on your Arduino
//
/////////////////////////////////////////////////////

#define EEPROM_ENABLE 1
//#undef EEPROM_ENABLE

// This is the alternate autorun. It overrides the SD card program 
//#define EEPROM_AUTORUN 1
#undef EEPROM_AUTORUN

#ifdef EEPROM_ENABLE
#include <EEPROM.h>
int eepos = 0;
static const byte EEPROM_TOTAL_MSG[]           PROGMEM = " EEPROM total: ";
static const byte EEPROM_AVAILABLE_MSG[]       PROGMEM = " EEPROM free : ";
static const byte EEPROM_GOING_MSG[]           PROGMEM = " EEPROM : ";
static const byte EEPROM_FORMAT_MSG[]          PROGMEM = " EEPROM clear";
#endif
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

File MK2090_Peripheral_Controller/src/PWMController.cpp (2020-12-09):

//////////////////////////////////////////////////////////
//
//  RetroRPN - "Электроника МК-90" reborn
//  Copyright (c) 2020 Mike Yakimov.  All rights reserved.
//  See main file for the license
//
//////////////////////////////////////////////////////////

#include "PWMController.hpp"
#include "Utilities.hpp"

//
// PWM Controller writes into port
// while converting 0-100% to 0-255
// 
void PWMController::begin( uint8_t Port){
    _port = Port;
    pinMode(_port, OUTPUT);
    digitalWrite(_port, LOW);
}

//
// Performs conversion from command string and sets duty cycle
//
void PWMController::set( const char* command){
    set( _convert3Digits( command));
}
void PWMController::set( uint8_t dc){
    dutyCycle = dc;
    if( dutyCycle>100) dutyCycle = 100;
    uint16_t d = (uint16_t)dutyCycle * 255 / 100;
    if( d < 10){
        digitalWrite(_port, LOW);
        return;
    }
    if( d >= 255){
        digitalWrite(_port, HIGH);
        return;
    }
    analogWrite( _port, d);
}

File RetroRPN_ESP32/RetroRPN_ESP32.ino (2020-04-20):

////////////////////////////////////////////////////////

/* RetroRPN - "Электроника МК-90" reborn
  Copyright (c) 2019 Pavel Travnik.  All rights reserved.

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
 Inspired by work of: 
    Gordon Brandly (Tiny Basic for 68000)
    Mike Field (Arduino Basic)
    Scott Lawrence (TinyBasic Plus)
    Brian O'Dell (INPUT)
    David A. Mellis (SD card utils)
    Oli Kraus (LCD library)
    Mike Yakimov (TinyBasic with real numbers)
    Andrey Skvortsov (Terminal-BASIC and Arduino SRAM)
    David Boucher (Tiny Keyboard)
    User "Dita Schop" (Arduino RPN calc)
*/

////////////////////////////////////////////////////////
//
// This implementation is for ESP32 Dev Module version 1
//
// Pin assignment:
//
// 01 - TX0
// 02 - In-built LED (SD activity)
// 03 - RX0
// 04 - SD insert sensor (DET_A)
// 05 - VSPI CSO - SD Select (DAT3)
//
// 06 - NA (Dev module not exposing)
// 07 - NA (Dev module not exposing)
// 08 - NA (Dev module not exposing)
// 09 - NA (Dev module not exposing)
// 10 - NA (Dev module not exposing)
// 11 - NA (Dev module not exposing)
//
// 12 - HSPI MISO LCD Data (R/W)
// 13 - HSPI MOSI LCD Reset (RESET)
// 14 - HSPI CLK LCD Clock (E)
// 15 - HSPI CSO LCD Select (RS)
// 16 - RX2 (serial to Pro Micro 8) Note Pro Micro 14, 15, 16 are SPI/burn
// 17 - TX2 (serial to Pro Micro 9)
// 18 - VSPI CLK - SD Clock (CLK)
// 19 - VSPI MISO - SD out (DAT0)
//
// 20 - NA (Dev module not exposing)
//
// 21 - LCD LED PWM
// 22 - LCD POWER (this model does not have sleep)
// 23 - VSPI MOSI - SD command (CMD)
//
// 24 - NA (Dev module not exposing)
//
// 25 - KBD CLK
// 26 - KBD RST
// 27 - KBD_LED CLK

// 28 - NA (Dev module not exposing)
// 29 - NA (Dev module not exposing)
// 30 - NA (Dev module not exposing)
// 31 - NA (Dev module not exposing)

// 32 - KBD_LED RST
// 33 - KBD DATA
// 34 - POWER ON/OFF
// 35 - (input only) Pro Micro active
//
////////////////////////////////////////////////////////

//#define __DEBUG

#include "ESP32Host.hpp"

static ESP32Host host;

void setup(void) {
  Serial.begin(SERIAL_HARD_BAUD_RATE); // this is to prevent garbage at start-up
  delay(120);
  while( Serial.available()) Serial.read();
  #ifdef __DEBUG
  unsigned long dt = millis();  
  dt = host.init() - dt;
  Serial.print("Init completed in ");
  Serial.print(dt);
  Serial.println(" ms");
  #else
  host.init();
  #endif  
}

void loop(void) {
  host.tick();
}

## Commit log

2019-10-16 Separated Encoder class
2019-10-16 Added code for timer scan
2019-10-16 Added timer scan
2019-10-23 Soft SPI SD card for the development board only
2019-10-23 Created Arduino project
2019-10-24 Added KiCAD drawings and schematics
    [MK2090-TRV01.GBL, MK2090-TRV01.GBS, MK2090-TRV01.GTL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]
2020-02-26 Created ESP32 port for the new hardware
    [CP1258.ods]
2020-02-26 Typo in the name
    [CP1251.ods]
2020-03-01 First working prototype
    4 arithmetic operations and full double parsing.
    [CP1251.ods]
2020-03-03 Added power management features
    [CP1251.ods]
2020-03-03 Added wiring diagram
2020-03-07 Added wiring diagrams
    [RetroCalculator.kicad_pcb, RetroCalculator.sch, RetroCalculator_Mockup2.sch]
2020-03-07 Added pin assignments
2020-03-07 Hardware update after Pro Micro 3.3V version
2020-03-09 Preprocessor tweaks for ESP32
2020-03-11 Fixed a minor bug with mouse middle button
    [Keyboard_Injector_Micro.ino]
2020-04-23 Added interface switch
2020-05-09 Added CLI switch
2020-07-08 Bug fixes, eliminate double redraw
    [BasicConsole.cpp, Editor.cpp, FileManager.cpp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]
2020-11-11 Updated for power management
2020-11-28 Added DS3231 board
2020-11-28 Fixed modification schematics
2020-11-28 Show wire cuts
2020-12-01 Reduced memory footprint
2020-12-09 Added Piezo and LCD PWM
2020-12-09 Added PCB files
    [MK2090_PERI_order-B_Cu.gbr, MK2090_PERI_order-B_Mask.gbr, MK2090_PERI_order-Edge_Cuts.gbr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]
